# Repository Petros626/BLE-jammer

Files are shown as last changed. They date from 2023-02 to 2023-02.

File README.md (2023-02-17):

# Bluetooth Low Energy jammer with 3D-printed case in usage with Arduino Nano Every
BLE (Bluetooth low energy) jammer using nRF24L01+ modules and an Arduino Nano Every combined in a 3D printed case.

## Brief overview
This repository is based on the original one by Wilson Ler (https://github.com/lws803/BLE-jammer) ,but provides a handy 3D case to house all the electronics and migrate the code (detailed commented) to the Arduino Nano Every.

## Project components
1. 1x Arduino Nano Every or Arduino Nano
2. 3x nRF24L01+ modules
3. 1x Mini-Breadboard
4. several Jumper wires
5. 1x 3D printed case
6. 4x M3 thread insert

## GPIO adjustment
Arduino Nano Every:

| Function:  | Pin Name:| Wire color:|
| --- | --- | --- |
| Power  	 | 3V3  	  | red |
| Ground  	 | GND | black | 
| ADC0/CE | A0 | green |
| ADC1/CSN | A2 | white |
| ADC2/CE | A3 | green |
| ADC3/CSN | A4 | white |
| ADC5/SCK1  | D13 | yellow |
| ADC6/MISO1 | D12 | brown |
| ADC7/MOSI1 | D11 | orange |
| ADC8/CE | A5 | green |
| ADC9/CSN | A6 | white |

## Schematic

Schematic:

BLE-Jammer schematic

Snippet of the nRF24L01+ schematic with decoupling capacitor:

nRF24L01+ schematic

Note: The Schematic differs a little bit from the wires in the picture, but finally it depends on you, which colours you prefer. I soldered a 1,0 pF decoupling capacitor on the PCB, with a size of 0603 and not 0402 like in the datasheet.
<br />
<br />
<br />

## Images
3D printed case:





Note: The cylinders, which the Arduino shield is mounted is recuded by exactly 3mm (cylinder height = 5mm), but could be necessarry to recude a litlte bit more. I used a grinder to grind down the protruding filament until the micro-USB socket was level with the recess. Unfortunately, since I don't have further access to a 3D printer, I couldn't try out several designs with reduced cylinder height. If anyone identifies an optimal height for the design, please feel free to share it. I have also moved the holder for the Arduino Mini-Breadboard 0.9 mm to the right, so that nothing wobbles in the housing any more.

## nRF24L01+ module testing
The script [nRF24L01+_InspectionCode](https://github.com/Petros626/BLE-jammer/blob/master/nRF24L01%2B_InspectionCode.ino) is used to check the functionality of your nRF24L01+ modules. Generally some people had problems to run them without errors, so a good approach would be to check first your modules **one by one** with the expected output:
```
nRF24L01+ module:

EN_AA	  = 0x3f
EN_RXADDR = 0x02
RF_CH	  = 0x4c
RF_SETUP  = 0x03
CONFIG	  = 0x0f
``` 
If you get the same addresses for the registers the module is working.

## Run the jammer
With the 

```c++
printf("\nnRF24L01+ module 1:\n\n");
radio.printDetails();
```

function (https://nrf24.github.io/RF24/classRF24.html#adc95213ed4c8569a90eb33122e16cea6) it's easy to print the expected output for all of your three modules. It should similiar to this, after your powered up the Arduino and every wire connection is in the right place:
```
nRF24L01 module :

EN_AA		= 0x00
EN_RXADDR	= 0x03
RF_CH		= 0x02
RF_SETUP	= 0x0d
CONFIG		= 0x0e
```
```
nRF24L01 module 2:

EN_AA		= 0x0
EN_RXADDR	= 0x03
RF_CH		= 0x1a
RF_SETUP	= 0x0d
CONFIG		= 0x0e
```
```
nRF24L01 module 3:

EN_AA		= 0x00
EN_RXADDR	= 0x03
RF_CH		= 0x50
RF_SETUP	= 0x0d
CONFIG		= 0x0e
```
Auto acknowledgement should be set to 0 like in the debug information above and the only difference in configuration among the 3 modules should be the `RF_CH`.

# Outlook
As the author has already described, this jammer is used to block device detection; with devices that are already known, the jammer will probably have no effect. This requires a jammer that covers the entire frequency range of Bluetooth Low Energy.

A product that I bought and tested successfully:



https://de.aliexpress.com/item/1005003664010447.html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

I reccommend to buy this antenna (male connector is needed) too, because the default one has a poor range:

https://de.aliexpress.com/item/32978207284.html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

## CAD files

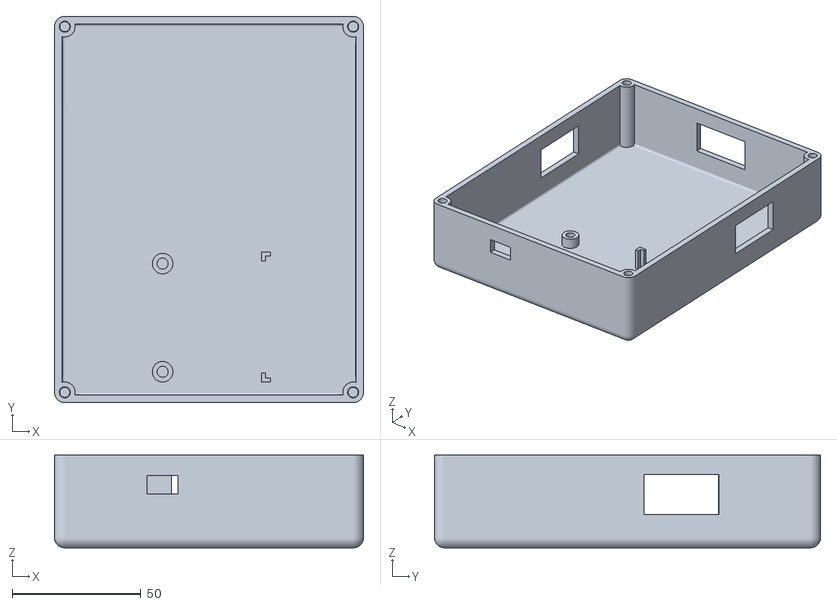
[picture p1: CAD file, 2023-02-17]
case.stl
120.0 x 150.0 x 36.0

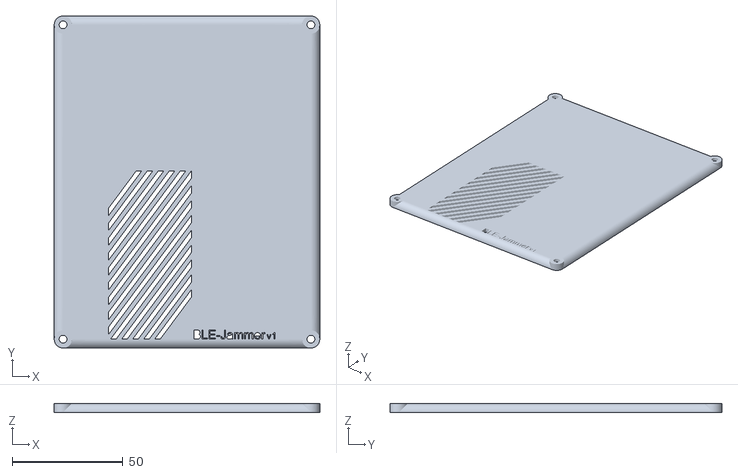
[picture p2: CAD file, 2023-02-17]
cover.stl
120.0 x 150.0 x 4.00

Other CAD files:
3D case for BLE-Jammer v4.f3d

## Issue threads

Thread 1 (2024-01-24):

Asking question

smoochiee, 2024-01-24:
What does this ble jammer do?and effect to device?how many meters

Petros626, 2024-08-01:
sorry for the late response. The function is the same like in the original repository. I didn't tried the maximum range, but in the data sheet, the effective range of the nRF24L01+ is mentioned.

Closed 2024-08-07.

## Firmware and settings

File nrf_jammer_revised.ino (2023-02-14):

/*
* Arduino nRF24L01+ Noise Gen
*                
* by Wilson
* revised by Petros
* Library: TMRh20/RF24, https://github.com/tmrh20/RF24/
* Documentation: https://nrf24.github.io/RF24/index.html
*/
#include <SPI.h>
#include <nRF24L01.h>
#include <RF24.h>
#include <printf.h>

// define LED
const int D13 = 13;
/**************************************************************
*	Name:		radio(), radio2(), radio3()
*	Func:		Constructor, Creates a new instance of this driver. 
Before using, you create an instance and send in the 
unique pins that this chip is connected to.
*	Return:	nothing
*************************************************************/
RF24 radio(A0,A1); // Pins from Nano Every for CE (PD3) & CSN (PD2) Pin of first nRF24L01+ module
RF24 radio2(A2,A3); // (PD1), (PD0) see above (second nRF24L01+ module)
RF24 radio3(A5,A6); // (PA3), (PD4) see above (third nRF24L01+ module)

void setup() 
{
  // set PE2 (D13) LED Pin as output
  pinMode(D13,OUTPUT);

/************************************************
*	Name:		begin()
*	Func:		Begin operation of the chip. Set the SPI
				pins MISO, MOSI and SCK.
*	Return:	bool: true = successful, false = failed
************************************************/
  radio.begin();
  radio2.begin();
  radio3.begin();

/******************************
*	Name:		powerDown()
*	Func:		Enter low-power mode.
*	Return:	nothing
******************************/
  radio.powerDown();
  radio2.powerDown();
  radio3.powerDown();
  
  // take 1s
  delay(1000);
  // turn off LED
  digitalWrite(D13,LOW);

/*first nRF24L01+*/
/*************************************************************
*	Name:		powerUp()
*	Func:		Leave low-power mode - 
required for normal radio operation after calling powerDown().
*	Return:	nothing
*************************************************************/
  radio.powerUp();

/******************************************************************
*	Name:		setAutoAck()
*	Func:		Enable (true) or disable (false) the auto-acknowledgement 
feature for all pipes.
*	Return:	nothing
******************************************************************/
  radio.setAutoAck(false);

/*****************************************************
*	Name:		setPALevel()
*	Func:		Set Power Amplifier (PA) level and Low Noise 
Amplifier (LNA) state
*	Return:	nothing
*****************************************************/
  radio.setPALevel(RF24_PA_HIGH);

/************************************************
*	Name:		setDataRate()
*	Func:		How fast data moves through the air. 
Units are in bits per second (bps).
*	Return:	bool: true = successful, false = failed
************************************************/
  radio.setDataRate(RF24_2MBPS);

/*********************************************
*	Name:		stopListening()
*	Func:	  Stop listening for incoming messages
, and switch to transmit mode.
*	Return:	nothing
*********************************************/
  radio.stopListening();

/*********************************************
*	Name:		setChannel()
*	Func:	  Set RF communication channel. 
The frequency used by a channel is calculated as:
2400 MHz + <channel number>.

BLE Channel Number | Frequency Value
37 -> 2402 MHz = 2400 MHz + 2
38 -> 2426 MHz = 2400 MHz + 26
39 -> 2480 MHz = 2400 MHz + 80
*	Return:	nothing
*********************************************/
  radio.setChannel(2); // 2402 MHz
  delay(1000);

  // second nRF24L01+ (for info see above)
  radio2.powerUp();
  radio2.setAutoAck(false);
  radio2.setPALevel(RF24_PA_HIGH);
  radio2.setDataRate(RF24_2MBPS);
  radio2.stopListening();
  radio2.setChannel(26); // 2426 MHz
  delay(1000);

  // third nRF24L01+ (for info see above)
  radio3.powerUp();
  radio3.setAutoAck(false);
  radio3.setPALevel(RF24_PA_HIGH);
  radio3.setDataRate(RF24_2MBPS);
  radio3.stopListening();
  radio3.setChannel(80); // 2480 MHz
  delay(1000);

  // turn on LED
  digitalWrite(D13,HIGH);
  
  // Sets the data rate in bits per second (baud) for serial data transmission
  Serial.begin(9600);
  // print nRF24L01+ details
  printf_begin();

/*********************************************
*	Name:	  printDetails()
*	Func:	  Print a giant block of debugging 
information to stdout
*	Return:	nothing
*********************************************/
  printf("\nnRF24L01 module 1:\n\n");
  radio.printDetails();
  printf("\nnRF24L01 module 2:\n\n");
  radio2.printDetails();
  printf("\nnRF24L01 module 3:\n\n");
  radio3.printDetails();
  
}

void loop() 
{
  // random string for spaming the three channels
  // uint8_t = byte (original code using byte, but char also works)
  char spam[] = {"x"};

  /****************************************
  *	Name:		writeFast()
  *	Func:		writes PayLoad to the buffers
  *	Return:	int: 0 = failed, 1 = successful
  ****************************************/
  radio.writeFast(&spam, sizeof(spam)); // call by address
  radio2.writeFast(&spam, sizeof(spam));
  radio3.writeFast(&spam, sizeof(spam));
 
  
  

}

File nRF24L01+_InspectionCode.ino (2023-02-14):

/*
  If your serial output has these values same then Your nrf24l01 module is in working condition :
  
  EN_AA          = 0x3f
  EN_RXADDR      = 0x02
  RF_CH          = 0x4c
  RF_SETUP       = 0x03
  CONFIG         = 0x0f
  
  This code is under public domain
  
  Last updated on 23/01/19
  revised by Petros K. 
  https://dhirajkushwaha.com/elekkrypt
 */

#include <SPI.h>
#include <RF24.h>
#include <printf.h>

// select your CE & CSN Pins <-- Configure here FIRST
RF24 radio(A0, A1);

byte addresses[][6] = {"1Node", "2Node"};


void setup() 
{
/**************************************************************
*	Name:		radio(), radio2(), radio3()
*	Func:		Constructor, Creates a new instance of this driver. 
Before using, you create an instance and send in the 
unique pins that this chip is connected to.
*	Return:	nothing
*************************************************************/
  radio.begin();


/*****************************************************
*	Name:		setPALevel()
*	Func:		Set Power Amplifier (PA) level and Low Noise 
Amplifier (LNA) state
*	Return:	nothing
*****************************************************/
  radio.setPALevel(RF24_PA_LOW);
  

/*********************************************
*	Name:		openWritingPipe()
*	Func:	  Open a pipe for writing via byte array.
*	Return:	nothing
*********************************************/
  radio.openWritingPipe(addresses[0]);


/*********************************************
*	Name:		openReadingPipe()
*	Func:	  Open a pipe for reading.
*	Return:	nothing
*********************************************/ 
  radio.openReadingPipe(1, addresses[1]);


/*********************************************
*	Name:		startListening()
*	Func:	  Start listening on the pipes 
opened for reading.
*	Return:	nothing
*********************************************/ 
  radio.startListening();
  
  // Sets the data rate in bits per second (baud) for serial data transmission
  Serial.begin(9600);
  // print nRF24L01+ details
  printf_begin();


/*********************************************
*	Name:	  printDetails()
*	Func:	  Print a giant block of debugging 
information to stdout
*	Return:	nothing
*********************************************/
  printf("\nnRF24L01+ module:\n\n");
  radio.printDetails();
  
  
}

void loop() {
//  empty

}
